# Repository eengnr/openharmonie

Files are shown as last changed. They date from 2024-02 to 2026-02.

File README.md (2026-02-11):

# openHARMONIE - OPEN source Home Automation ReMote cONtrol Infrared Emitter

⚠️ Work in progress ⚠️

## Goal

With this project the Logitech Harmony Hub should be rebuilt as a proof of concept.

It should be possible to start different activities (watch TV, watch Fire TV, watch Bluray, ...) from a web UI/app (virtual openHARMONIE remote), voice commands or a physical remote.

## Motivation and background

The Logitech Harmony was deprecated a few years ago, no new hardware is sold anymore. The servers are still running, but it's not clear how long this will be the case.

My home automation heavily relies on the integration of the Harmony into openHAB, e.g. to automatically dim/brighten lights if a stream is played on the Fire TV (done with complicated adb magic...).
Or to mute certain notification events on the LaMetric time while watching TV/streaming.

Additionally I have a complex setup with HDMI switches and splitters for sound and a self built Ambilight clone.

That's why I'm looking for an alternative. And what could be better than building it on my own :)

## Overview

- Logic implementation (which activity needs which devices in which states, ...) will be done with openHAB running on a Raspberry Pi 5.
- Sending of IR commands to devices will be done with a Raspberry Pi Zero W.
- Receiving of IR commands will also be done with the Pi Zero W.
- Communication between both Raspberrys will be done with MQTT.

### Current state of project

- ✅ Hardware setup
- ✅ MQTT setup
- ✅ Recording of IR commands from physical remotes
- ✅ Send remote control command from openHAB to a device
- ✅ Receive remote control command from additional physical remote
- ✅ Activity logic
- ✅ UI on smartphone (openHAB sitemaps)
- ✅ Voice commands
- 0️⃣ 3D printed housing
- 0️⃣ Refactor code to node modules
- 🚧 Refactor documentation and move to a repository
- ✅ Add pictures to the documentation
- 🚧 Bluetooth support

## Prerequisites

Building this is for experts and a good amount of time, nerves and coffee is necessary.
It took me almost three months to figure everything out and implement it.

### Skills and basic software setup

- openHAB (openHABian) is set up and running on Raspberry Pi 5 (Bookworm with openHAB 5.1.1)
- openHAB has the JavaScript binding installed and the openhab_rules_tools
- Knowledge about how to use openHAB is already available
- Raspbian Lite is set up and running on Raspberry Pi Zero W (Bullseye, Bookworm does not work properly for this as of March 2025!)
- Knowledge about basic Linux commands is already available
- Knowledge how to solder stuff on a circuit board is already available

### Necessary hardware

- Raspberry Pi 5 (or anything else where openHAB is running)
- Raspberry Pi Zero W
- Raspberry Pi Pico W (for optional Bluetooth)
- IR Receiver VS1838B
- IR LEDs (3 at least)
- some resistors
- 2N2222 transistor
- some (2-wire) cables
- circuit board for IR hardware
- Micro USB to Micro USB cable to connect the Zero and Pico
- soldering equipment
- spare remote control, e.g. from a no longer used TV (will be the "physical" openHARMONIE remote control)

## Basic MQTT Setup

- Broker (Mosquitto) is running on openHAB Raspberry Pi
- openHAB is Publisher (MQTT Client)
- Shell Script on Pi Zero W is Subscriber (MQTT Client)

Note: with this setup, you can easily add multiple Pi Zero W for different rooms and control them all from openHAB.

### Setup MQTT Broker (running on openHAB Raspberry Pi 5)

- Install `mosquitto`:

  `$ sudo apt update && sudo apt install mosquitto` (possible via openhabian-config as well)

- Configure mosquitto:

  `$ sudo vi /etc/mosquitto/conf.d/local.conf`

  Add lines:
    ```bash
    listener 1883
    allow_anonymous false
    password_file /etc/mosquitto/credentials
    ```

- Create credentials for openHAB client and shell script client (optional):

  `$ sudo mosquitto_passwd -b /etc/mosquitto/credentials pi pi`

  `$ sudo mosquitto_passwd -b /etc/mosquitto/credentials oh oh`

- Restart broker

  `$ sudo systemctl restart mosquitto`

### Setup openHAB MQTT (Client)

- Install MQTT Binding
- Add Bridge MQTT Broker with IP 127.0.0.1 and `oh`/`oh` as user/password
- Add Thing topic for sending IR commands to devices (topic to publish)
- Add a channel to this thing
- Add Thing topic for receiving IR commands from additonal hardware remote control (optional, topic to subscribe)
- Add a channel to this thing

Note: We use two separate topics instead of one topic with a commandTopic and stateTopic, because communcation is fire & forget. There is no direct "response" to the stateTopic after the commandTopic was published.

See `/etc/openhab/things/mqttopenharmonie.things`

- Create an item for the `Pi0WHarmonie` channel which can later be updated from rules
- Create an item for the `OHHarmonie` channel which can later be used to process context specific IR commands from the additional hardware remote

See `/etc/openhab/items/openharmonie.items`

### Setup Pi Zero W MQTT (Client)

- Install `mosquitto_sub`:

  `$ sudo apt install mosquitto-clients`

### Test the setup

Note: Use the IP of the openHAB Raspberry Pi where `mosquitto` is running instead of `broker.home`.

On Pi Zero W:

- Subscribe to the topic

  `$ mosquitto_sub -h broker.home -t devices/pi0w/harmonie -u pi -P pi`

In openHAB:

- Open API Explorer -> Items -> POST /items/{itemname} -> Try out
- Enter the item name `Send_Harmonie_Command` created above
- Enter string `hello world` in request body
- Execute (= publish to the topic)

➡️ `hello world` is shown on the Pi Zero W command line

## openHAB configuration

For openHAB we need several Things, Items and Rules. Additionally a Sitemap is necessary.

### Communication to Pi Zero W

- 2 String Items for publishing/subscribing to MQTT topics.
These necessary items were already created in the previous step for the MQTT setup.

### Physical remote controls

Necessary for each physical remote control belonging to a physical device:
- 1 Number Item which has all the buttons of the remote as metadata and updates the `Send_Harmonie_Command` MQTT String Item with the `DEVICE BUTTON` combination to be sent

  `TV_HISENSE_EN2BF27H_RemoteControl`, `BLURAY_PLAYER_PIONEER_RemoteControl`, ...

### Physical devices

Necessary for each physical device (TV, Receiver, HDMI switches ...)
- 1 Switch item for power state. The item only reflects the current power state, it is not used to control it.

  `TV_HISENSE_EN2BF27H_OnOff`, `BLURAY_PLAYER_PIONEER_OnOff`, ...

Note: if the "physical remote" number Item of the device is updated directly via UI (i.e. "a button is pressed on the physical remote"), the switch Item is NOT changed. That's how we can correct device status if IR commands failed

### Virtual openHARMONIE remote

- 1 Number item `OPENHARMONIE_RemoteControl` for the buttons on the virtual openHARMONIE remote, which will be used to control the devices based on the current activity

### Activities

Necessary for Activities (Watch TV, watch Fire TV, ...)
- 1 String Item "Activity starting" which gets an update as soon as an activity is starting

  `OPENHARMONIE_Activity_Starting`

- 1 String Item "Activity started" which gets an update as soon as an activity is fully started

  `OPENHARMONIE_Activity_Started`

Activites are triggered with the `Starting` item. This equals the activity starting channel of the real Harmony.
If the activity is started, we execute different phases and queue their tasks with a `Gatekeeper` from the `openhab_rules_tools`.
These phases are defined for each activity:

- `onExit`: tasks to do before the current activity is changed
- `powerStates`: tasks to set the correct power states for the new activity
- `inputStates`: tasks to set the correct input states for the new activity
- `onEnter`: tasks to do to finish starting the activity
- `onFinish`: tasks which can dynamically be added, e.g. to directly start a favorite TV programm or app

All possible activities are predefined in the metadata of the `OPENHARMONIE_Activity_Starting` item to be selected from the UI.

Activities can then be triggered either by buttons of the physical/virtual openHARMONIE or by voice commands (or anything else available in openHAB).

### Sitemap

We need some additional groups to add the virtual remotes of the devices to a sitemap.

See `/etc/openhab/etc/sitemaps/openharmonie.sitemap`

Note: The sitemap uses icons which are saved in `/etc/openhab/icons/classic`. This was the only way to get the icons in the openHAB Android app and in the Basic UI.

The sitemap includes a web view to load a CSS for the Basic UI.

Additionally, the sitemap uses light controls which are not part of the setup here.

### Voice commands

We need a group with switches which will be available via Matter. openHAB acts as a Matter Bridge and provides the switches.

See `/etc/openhab/etc/items/openharmonie.items`

### Rules

Necessary rules:
- Rule to send a remote control command to the Pi Zero W if a remote control button was pushed (`Remote_Control_Button_Pushed`) (= update MQTT Item with state if a remote control item changes its state)
- Rule to process an incoming IR command via MQTT from the physical openHARMONIE (`IR_Command_Received_Via_MQTT`)
- Rule to send a command to a target device if the button on the physical/virtual openHARMONIE was pushed (`openHARMONIE_Button_Pushed`)
- Rule to start an activity (`openHARMONIE_Activity_Starting`)
- Rule for voice commands (`openHARMONIE_Voice_Commands`)

Rules are written in JavaScript.

### Implementation

Note that some Items (e.g. groups for TV/Reciever, light controls) already exist in my setup from other configuration files.

#### Things

See `/etc/openhab/items/mqttopenharmonie.items`

#### Items

See `/etc/openhab/items/openharmonie.items`

#### JavaScript rule

See `/etc/openhab/automation/js/openharmonie.js`

#### Sitemaps

See `/etc/openhab/sitemaps/openharmonie.sitemap`

## Pi Zero W configuration

### Setup a non-root user

- Add a new user with name `openharmonie`

  `$ sudo adduser openharmonie`

- Enter `openharmonie` as password and confirm all other values

- Add the user to the groups `dialout` to send commands via serial connection

  `$ sudo adduser openharmonie dialout`

- Add the user to the group `video` to send commands via IR

  `$ sudo adduser openharmonie video`

Note: The files will be placed in the `pi` user home folder and owned for simplicity.

### Move `/tmp/` folder to RAM

Add the following line in `/etc/fstab`.

`$ sudo vi /etc/fstab`

```
tmpfs /tmp tmpfs defaults,size=64M 0 0
```

### Listener for MQTT commands

#### Shell script as MQTT client

A shell script `openharmonie.sh` is running on the Pi Zero W which is receiving MQTT updates and calls another script to send out IR commands (or adb commands for Fire TV).

The script watches if the `mosquitto_sub` process is still running every 5 seconds; if not, the script exits.

`$ touch ~/openharmonie/openharmonie.sh && chmod +x ~/openharmonie/openharmonie.sh`

See `/home/pi/openharmonie/openharmonie.sh`

#### Turn the MQTT shell script to a system service

- Create a new file `openharmonie.service` in `~/openharmonie`

  See `/home/pi/openharmonie/openharmonie.service`

- Copy the file to the `systemd` configuration folder

  `$ sudo cp openharmonie.service /etc/systemd/system`

- Reload the systemd configuration

  `$ sudo systemctl daemon-reload`

- Enable and start the mqtt subscriber service

  `$ sudo systemctl enable openharmonie.service`
  
  `$ sudo systemctl start openharmonie.service`

- Check that it's running

  `$ systemctl status openharmonie.service`
  ```
  ● openharmonie.service - MQTT Subscriber for remote control commands
      Loaded: loaded (/etc/systemd/system/openharmonie.service; enabled; vendor preset: enabled)
      Active: active (running) since Fri 2024-01-12 12:53:06 CET; 4s ago
    Main PID: 22855 (openharmonie.sh)
        Tasks: 5 (limit: 414)
          CPU: 94ms
      CGroup: /system.slice/openharmonie.service
              ├─22855 /bin/bash /home/pi/openharmonie/openharmonie.sh
              ├─22856 /bin/bash /home/pi/openharmonie/openharmonie.sh
              ├─22857 /bin/bash /home/pi/openharmonie/openharmonie.sh
              ├─22859 sleep 5
              ├─22860 mosquitto_sub -h broker.home -t devices/pi0w/harmonie -u pi -P pi
              └─22931 sleep .1

  Jan 03 13:35:20 pi0w systemd[1]: Started MQTT Subscriber for remote control commands.
  Jan 03 13:35:20 pi0w openharmonie.sh[18885]: Listening...
  ```

### Setup for infrared on Raspberry Pi Zero W

Note that `LIRC` is not necessary on Bullseye. Instead, the kernel already supports multiple IR protocols.

Receiving/sending can be done with `ir-keytable` and `ir-ctl` on Bullseye.

#### Hardware setup

##### Record commands

- VS1838B IR Receiver

1) Connect VCC of IR Receiver to Raspberry Pi Zero W GPIO 5V
2) Connect GND of IR Receiver to Raspberry Pi Zero W GPIO Ground
3) Connect OUT of IR Receiver to Raspberry Pi Zero W GPIO 17

##### Send commands

- 5mm IR Emitter LED (IF = 20 mA, UF = 1.2 to 1.5 V)
- Resistor with (5 V - 1.2 V) / 20 mA = 175 to 190 Ohm (1.5 to 1.2 V LED voltage range)
- 2N2222 transistor
- 1 kOhm resistor for transistor

Connect IR LED to 5 V pin and use a transistor as switch. The transistor is toggled by the GPIO 18 pin.
1) Connect the 190 Ohm resistor to 5 V pin
2) Connect anode of LED to resistor
3) Connect cathode of LED to collector of 2N2222 transistor
4) Connect emitter of transistor to GND pin
5) Connect 1 kOhm resistor to GPIO 18 and base of transistor

Note: You can use three IR Emitter LEDs in a row. The resistor then has to be changed to be in the range of 27 - 75 Ohm (1.5 to 1.2 V LED voltage)
If more than three LEDs are necessary, they have to be put parallel to the existing three. More current is then drawn from the 5 V pin. Research needs to be done how high this current can be :)

##### Wiring diagram

Wiring Diagram

The wiring diagram shows the setup with three IR leds and two resistors with 22 and 10 Ohm.

#### Software setup

##### Enable GPIO pins

- Boot Raspberry Pi Zero W and edit the boot config with the editor of your choice, e.g.

  `$ sudo vi /boot/config.txt`

- Uncomment lines:

  ```
  dtoverlay=gpio-ir,gpio_pin=17
  dtoverlay=gpio-ir-tx,gpio_pin=18
  ```

- Save & exit vi, then reboot

The IR Receiver and IR LED are now controllable with GPIO pin 17 and 18.

##### Setting up symlinks for /dev/lirc0 and /dev/lirc1

The IR receiver/sender devices are randomly assigned at boot by the kernel to devices `/dev/lirc0` and `/dev/lirc1`, that's why we create symlinks for them.
With the symlinks, we have a static name for the devices.

- Get attributes for `/dev/lirc0`

  `$ udevadm info --attribute-walk --path $(udevadm info --query path --name=/dev/lirc0)`

- Get attributes for `/dev/lirc1`

  `$ udevadm info --attribute-walk --path $(udevadm info --query path --name=/dev/lirc1)`

With this we get the `DRIVERS=="gpio_ir_recv"` and `DRIVERS=="gpio-ir-tx"`.

Note the dashes and minus for the DRIVERS!

With this information, we can create a udev configuration file.

- Create a file `/etc/udev/rules.d/80-lirc.rules` with the following content:

  `$ sudo vi /etc/udev/rules.d/80-lirc.rules`
    ```
    SUBSYSTEM=="lirc", KERNEL=="lirc*", DRIVERS=="gpio-ir-tx", SYMLINK+="lirc-tx"
    SUBSYSTEM=="lirc", KERNEL=="lirc*", DRIVERS=="gpio_ir_recv", SYMLINK+="lirc-recv"
    ```

- Then save and exit and reboot the Pi.

  `$ sudo reboot`

After the reboot, the IR receiver should be available at `/dev/lirc-recv` and the IR sender should be available at `/dev/lirc-tx`.

```bash
$ ls -l /dev/lirc*
crw-rw---- 1 root video 251, 0 Dec 30 09:56 /dev/lirc0
crw-rw---- 1 root video 251, 1 Dec 30 09:56 /dev/lirc1
lrwxrwxrwx 1 root root       5 Dec 30 09:56 /dev/lirc-recv -> lirc1
lrwxrwxrwx 1 root root       5 Dec 30 09:56 /dev/lirc-tx -> lirc0
```
We can now use `/dev/lirc-tx` to send IR signals and `/dev/lirc-recv` to receive commands.

##### Record IR commands

- Install `ir-keytable`

  `$ sudo apt install ir-keytable`

Note: at time of writing, version `1.20.0` of `ir-keytable` is used.

- Confirm it's running

  `$ ir-keytable`
    ```bash
    Found /sys/class/rc/rc1/ with:
        Name: gpio_ir_recv
        Driver: gpio_ir_recv
        Default keymap: rc-rc6-mce
        Input device: /dev/input/event0
        LIRC device: /dev/lirc1
        Attached BPF protocols: Operation not permitted
        Supported kernel protocols: lirc rc-5 rc-5-sz jvc sony nec sanyo mce_kbd rc-6 sharp xmp imon
        Enabled kernel protocols: lirc rc-5 rc-5-sz jvc sony nec sanyo mce_kbd rc-6 sharp xmp imon
        bus: 25, vendor/product: 0001:0001, version: 0x0100
        Repeat delay = 500 ms, repeat period = 125 ms
    ```

In the example above, the IR receiver is recognized as `/dev/lirc1` and available via the kernel as `rc1`.
This may change after each reboot. We use `rc1` for the following commands.

- Enable all supported kernel protocols for the test

  `$ sudo ir-keytable -p all -s rc1`

- Start the `ir-keytable` test and send an IR command from the remote to the IR receiver.
This is the input of the IR receiver already passed through the kernel.

  ```bash
  $ ir-keytable -t -s rc1
  Testing events. Please, press CTRL-C to abort.
  1253.120088: lirc protocol(rc5): scancode = 0x1c3d toggle=1
  1253.120135: event type EV_MSC(0x04): scancode = 0x1c3d
  1253.120135: event type EV_SYN(0x00).
  1253.230098: lirc protocol(rc5): scancode = 0x1c3d toggle=1
  1253.230144: event type EV_MSC(0x04): scancode = 0x1c3d
  1253.230144: event type EV_SYN(0x00).
  1254.250104: lirc protocol(rc5): scancode = 0x1c3b
  1254.250150: event type EV_MSC(0x04): scancode = 0x1c3b
  1254.250150: event type EV_SYN(0x00).
  1255.440082: lirc protocol(rc5): scancode = 0x1c1f toggle=1
  1255.440121: event type EV_MSC(0x04): scancode = 0x1c1f
  1255.440121: event type EV_SYN(0x00).
  ...
  ```

Test different keys of remote. If the the keycodes are different for different remote control buttons, the kernel can decode the IR signal.

➡️ See section "Codes for supported remotes"

If the keycodes are the same for every button, then the kernel does not support the remote protocol and raw codes need to be captured

➡️ See "Raw codes for unsupported remotes"

###### Codes for supported remotes

If the kernel supports the remote control protocol, the key codes can be written down in a `toml` configuration file for each remote.

While running `$ ir-keytable -t -s rc1`, press each button of the remote and note down its hex code and the protocol of the remote (see example above).
The kernel already decodes the IR command.
Write this into a `toml` file for your remote, e.g.

`/home/pi/openharmonie/remotes/toml/HAUPPAUGE_PTR005.toml`

If a remote sends two codes for each button press, we can note them as e.g. `REMOTE_POWER_1` and `REMOTE_POWER_2` in the `toml` file.

Note: the `toml` file can also be loaded to the kernel. Then it's possible to react to the IR control on the Raspberry Pi, e.g. power down the Raspberry Pi when `KEY_POWER` is pressed. If you want to control the Raspberry Pi with a remote control, you have to give key/button names which the kernel can map to commands (e.g. KEY_POWER will shut down the Pi).

We will use this to receive IR commands from a remote control which is not used by any device. The IR command received on the Pi Zero W can be sent to openHAB via MQTT and from there we can execute context specific commands. E.g. send back play/pause depending on the current activity to either the cable receiver, the Fire TV or the Bluray player via MQTT to the Pi Zero W.

###### Raw codes for unsupported remotes

If the kernel does not support the remote control protocol, the raw IR signal needs to be captured and transmitted. Capturing/sending has to be done in the `mode2` format. I couldn't get `toml` files with raw codes working.

All in all capturing the raw signals was really challenging most likely because of the "analogue" path from original remote control to the IR receiver.

- Capture a button press to a file in mode2 format

  `$ ir-ctl -d /dev/lirc-recv --mode2 --receive=REMOTE_POWER.txt`

- After the button on the remote was pressed, end the recording with `Ctrl+c`.

The file `REMOTE_POWER.txt` then contains multiple raw IR signals which consist of `pulse` and `pause` lines and are separated by a `timeout` between two signals.
The `timeout` is ignored during sending.

After the file for one button was recorded, test immediately if the signal can be sent to the device, see section "Sending commands not supported by the kernel" below.

If the device does not react correctly or not at all, try to record the raw signal again (e.g. try with longer/shorter button press). Repeat this until the device recognizes the command.

This can be really annoying and I had to capture the signals of the buttons several times until the signals were properly received at the device.

For some buttons, I even recorded their signal 10-20 times in separate files for each button press. Then I checked which of the files could be used to send the command to the device. From these files, I calculated the average pulse/pause length of each pulse/pause line and saved this in a new file. Then I tested if this "average length" file could be used to send the command, which was fortunately always ok.

##### Send IR commands

Sending is done with `ir-ctl`.

###### Sending commands supported by the kernel

Sending a code can be done with:

  `$ ir-ctl -d /dev/lirc-tx -k TV_HISENSE_EN2BF27H.toml -K REMOTE_POWER`

The configuration file and the button need to be passed.

If a remote sends two codes for a button press, we have to add them both with another `-K`:

  `$ ir-ctl -d /dev/lirc-tx -k BLURAY_PLAYER_PIONEER.toml -K BUTTON_1 -K BUTTON_2`

###### Sending raw commands not supported by the kernel

Sending a code can be done with:

  `$ ir-ctl -d /dev/lirc-tx --send=KEY_NAME.txt`

The file with the pulses and spaces needs to be passed.

##### Wrapper script to send commands of different remote controls

Now we bring all of this together in one script which can be called by the MQTT subscriber script running on the Raspberry Pi Zero W.

To realize this, put all files in a folder with the following structure. Supported remotes are put into the `toml` folder, unsupported remotes are put in the `raw` folder.

Additionally, for each device a shell script is written which gets the key name passed. In the script, the correct amount of codes to be sent has to be configured. Make the scripts executable with `chmod`.
Files which were not explained yet will be covered later.

```bash
~
|
- openharmonie
  |
  - mqttsubscriber.sh
  - mqttsubscriber.service
  |
  - remotes
    |
    - toml
    | |
    | - TV_HISENSE_EN2BF27H.toml
    | - BLURAY_PLAYER_PIONEER.toml
    | ...
    - raw
    | |
    | - RECEIVER_SAMSUNG_KD
    | | |
    | | - REMOTE_POWER.txt
    | | - REMOTE_MENU.txt
    | | - ...
    | - ...
    - thd
    | |
    | - openharmonie.conf
    |
    - keys
    | |
    | - keymap.sh
    | - keymap_fallback.sh
    |
    - receive_command.sh
    - send_command.sh
    - TV_HISENSE_EN2BF27H.sh
    - BLURAY_PLAYER_PIONEER.sh
    - RECEIVER_SAMSUNG_KD.sh
    - FIRETV.sh
    ...
```

Examples for different types of devices.

1) Remote control with raw codes:

    `/home/pi/openharmonie/remotes/RECEIVER_SAMSUNG_KD.sh`

2) Remote control with kernel supported codes:

    `/home/pi/openharmonie/remotes/TV_HISENSE_EN2BF27H.sh`

3) Remote control with mixed button behavior:

    - buttons which send a code `0xa6a7` first
    - buttons which send a code `0xa6a0` first
    - buttons which send the code once
    - buttons wich send the code twice

    `/home/pi/openharmonie/remotes/BLURAY_PLAYER_PIONEER.sh`

Additonally we create a `send_command.sh` shell script which is called from the MQTT listener:

  `$ touch ~/remotes/send_command.sh && chmod +x ~/remotes/send_command.sh`

  See `/home/pi/openharmonie/remotes/send_command.sh`

##### Receive IR commands from additional remote

An additional remote will be used to control the whole system depending on the current activity. For this we use a spare remote, e.g. from a device which is no longer used.

###### Reacting to IR input

- Create a `toml` file for this additional remote.
  See `/home/pi/openharmonie/remotes/toml/OPENHARMONIE_TV_PHILIPS.toml`

Note: To not control the Raspberry Pi Zero W with the button presses, we have to choose button names which are not used by the Linux system.
I chose `BTN_TRIGGER_HAPPY` keys and `KEY_MACRO` keys.

- To permanently load this file after a reboot, copy it to the folder `/etc/rc_keymaps`

  `$ sudo cp /home/pi/openharmonie/remotes/toml/OPENHARMONIE_TV_PHILIPS.toml /etc/rc_keymaps`

- Then add it in the `rc_maps.cfg`

  `$ sudo vi /etc/rc_maps.cfg`

  Add the following line to the existing maps:
  ```
  ...
  # Table to automatically load the rc maps for the bundled IR's provided with the
  # devices supported by the linux kernel

  #driver table                    file
  gpio_ir_recv    *       OPENHARMONIE_TV_PHILIPS.toml
  ...
  ```

Now the IR commands sent by the remote can be processed as input events.

###### Processing input events with triggerhappy

Processing the input events is done with `triggerhappy`. The same keycodes have to be used like in the openHARMONIE `toml` file.

- Create a configuration file for `triggerhappy`

  `/home/pi/openharmonie/remotes/thd/openharmonie.conf`

- Copy the file to the triggerhappy config folder

  `$ sudo cp /home/pi/openharmonie/remotes/thd/openharmonie.conf /etc/triggerhappy/triggers.d`

- Restart the triggerhappy service

  `$ sudo systemctl restart triggerhappy.service`

Every input event triggered by the remote executes the `receive_command.sh` with the generic button name.

###### Forwarding input events via MQTT

Forwarding the button name via MQTT to openHAB can be done with a script.

- Create it in the remotes folder

  `$ touch ~/remotes/receive_command.sh && chmod +x ~/remotes/receive_command.sh`

  See `/home/pi/openharmonie/remotes/receive_command.sh`

Note: If using DNS names to communicate with the MQTT broker, it's recommended to install `dnsmasq` to have a DNS cache.
Otherwise, each time the `mosquitto_pub` is called a DNS lookup is necessary which can cost time.

  `$ sudo apt install dnsmasq`

Then reboot the Pi Zero W. If everything works, you should see an update of the `Receive_Harmonie_Command` item after pressing a button on the remote.

### Setup connection to Fire TV

The Fire TV can be controlled with adb and Bluetooth.
We will use a mixture depending on the commands.

- Install `adb` on the Pi Zero W

  `$ sudo apt install adb`

- Start the Fire TV and activate developer options somewhere in the settings menu

- Execute the following command to initialize the connection

  `adb connect firetv.home:5555`

  Note: Change `firetv.home` to the IP address of your Fire TV

- A popup is shown on the Fire TV, make sure to set the checkmark and accept the incoming connection.

From now on, we can connect to adb, execute commands and disconnect if the Fire TV is not used.

To control the Fire TV, we will use `adb shell sendevent` to send keycodes to the keyboard input device available on the Fire TV.

This is faster than `adb shell input keyevent` because it doesn't use the Java layer of Android.

Note: This input device `amzkeyboard` suddenly disappeared from my Fire TV after a few days. That's why I added the `input keyevent` as fallback.

With `adb shell sendevent` we can send the key codes available from the Linux kernel: https://github.com/torvalds/linux/blob/master/include/uapi/linux/input-event-codes.h

If the `amzkeyboard` input is not available, we use `input keyevent` as fallback. For this we need to map the key codes of the Linux kernel to the key events of Android: https://developer.android.com/reference/android/view/KeyEvent

To start specific apps, we will use `adb shell am start`.

- Create a shell script for Fire TV commands on the Pi Zero W and make it executable

  `$ touch ~/remotes/FIRETV.sh && chmod +x ~/remotes/FIRETV.sh`

  See `/home/pi/openharmonie/remotes/FIRETV.sh`

- Additionally create two keymap files to look up the numbers of the key names. One for the Linux key codes, the other one to map them to Android key events.

  See `/home/pi/openharmonie/remotes/keys/keymap.sh` and `/home/pi/openharmonie/remotes/keys/keymap_fallback.sh`

Note: The correct activites for apps can be found via adb:

- Connect to the Fire TV

  `$ adb connect firetv.home:5555`

- Search the package name, e.g. for an app called `streamingapp`

  `$ adb shell pm list packages | grep streamingapp`

- If the app cannot be found, list all packages and search it manually

  `$ adb shell pm list packages`

- Get the activity

  `$ adb shell cmd package resolve-activity --brief com.mystreamingapp.app`

- If no activity can be found, try

  `$ adb shell pm dump com.mystreamingapp.app | grep -A 1 "MAIN" | grep com.mystreamingapp.app`

Note: the supported keycodes for the `amzkeyboard` input can be found with
`$ adb shell getevent -lp`

Note:
Sending the `input keyevent` is quite slow, because the `input.jar` needs to be started every time.
Sending an event with `sendevent` is faster, but for this the virtual keyboard must be available.
As an alternative to the virtual keyboard, the `sendevent` can be sent to the device which appears if the Fire TV remote was used.
But this is not always available.
The best way to control the Fire TV is via Bluetooth. The `FIRETV.sh` tries to use the best available way to send the commands.

### Setup Linux laptop

If `HDMI` is started as activity, a Linux laptop can be controlled.
To be able to do this, `ydotool` needs to be installed on the Linux laptop and `ssh` access from the Pi Zero W to the laptop needs to be set up.

On the Linux laptop:

- Install `ydotool`

  `$ sudo apt update && sudo apt install ydotool`

On the Pi Zero W:

- Login as `openharmonie`

  `$ su - openharmonie`

- Create a ssh key

  `$ ssh-keygen -t ed25519 -C "openharmonie"`

- Copy the public key to the laptop (exchange user and host accordingly)

  `$ ssh-copy-id user@linux.home`

- Create an alias

  `$ vi .ssh/config`
  ```
  Host linux
      User user
      IdentityFile ~/.ssh/id_ed25519
      HostName linux.home
      PreferredAuthentications publickey
  ```

- Logout from `openharmonie`

  `$ exit`

## Pi Pico W configuration

The Pi Pico W acts as a Bluetooth keyboard to send commands to a Fire TV.
It receives the key to send via a serial USB connection from the Pi Zero W.
With the provided sketch, it's possible to pair and connect only one device.

See `openHARMONIE.ino`.

TODO: Make it possible to pair multiple devices and connect only the one which is relevant for the current activity.

### Flash software to Pi Pico W

- Download and install Arduino IDE: https://www.arduino.cc/en/software

- Open Arduino IDE and go to `File` > `Preferences...` > `Additional Boards Manager URLs`. Paste `https://github.com/earlephilhower/arduino-pico/releases/download/global/package_rp2040_index.json` there and click `OK`.

- Open the `openHARMONIE.ino` sketch.

- Go to `Tools` > `Board` > `Boards Manager...`, search for `Raspberry Pi Pico` and click `INSTALL`.

- Connect the Pico W with a USB cable to your computer which is running Arduino IDE.

- In the `Select Board` dropdown, go to `Select Other Board and Port`, select `Raspberry Pi Pico W` in the Boards list. The port should be discoverd as `/dev/ttyACM0` on Linux.

- Go to `Tools` > `IP/Bluetooth Stack` and select `IPv4 + Bluetooth`.

- Click the `Verify` checkmark and if no errors are shown, click the `Upload` checkmark to flash the code to the Pi Pico W.

- After this you should see a device `openHARMONIE` e.g. in the Bluetooth pairing menu of your mobile phone (but don't connect to it).

### Add named device to Pi Zero W

Simlar to the IR sender/receiver devices a named device for the serial connection between Pi Zero W and Pi Pico W is created.

- Create a file `/etc/udev/rules.d/80-pico.rules` with the following content:

  `$ sudo vi /etc/udev/rules.d/80-pico.rules`
    ```
    KERNEL=="tty*", ATTRS{manufacturer}=="Raspberry Pi", ATTRS{product}=="Pico W", SYMLINK+="picow"
    ```

- Then save and exit and shut down the Pi Zero W.

- Connect the Pi Zero W and Pi Pico W with a Micro USB to Micro USB cable. Use the USB port on the Pi Zero W which is not used for power.

- Start up the Pi Zero W. The serial device should be available as `/dev/picow` and can be used by the `FIRETV.sh`.

### Connect Fire TV to Bluetooth device

- In the settings of the Fire TV, go to Bluetooth and game controllers and search for a new device named `openHARMONIE`.

- Connect to it!

## Voice commands integration

To make everything controllable from voice commands, the Matter binding needs to be installed in openHAB.
Please check the documentation how to install it and connect it to your voice assistant, e.g. an Amazon Echo, Google Nest or Apple Homepod.

After installation of the Matter binding, openHAB acts as a Matter bridge and can expose items to the Matter fabric.

For every command (e.g. start an activity, start a favorite, pause, play, ...) we need a Switch item with Matter `OnOffLight` metadata.

Note: It's only possible to expose lights or power outlets as controlees via Matter.

The switch items are part of a group and the items can then be discovered e.g. in the Alexa app. Afterwards, if necessary a routine can be created for a specific switch as voice command.

E.g. for "Pause with openHARMONIE" create a routine which then turns the "Pause" toggle to ON and so on.

The same should be possible with a Google Nest or Apple Homepod.

## Starting up

After everything is configured and set up, place the Raspberry Pi Zero W somewhere where it has WIFI access and point the IR LEDs towards your devices.
It's best if the distance to the devices is short.

Then have fun with your new setup!

## Images

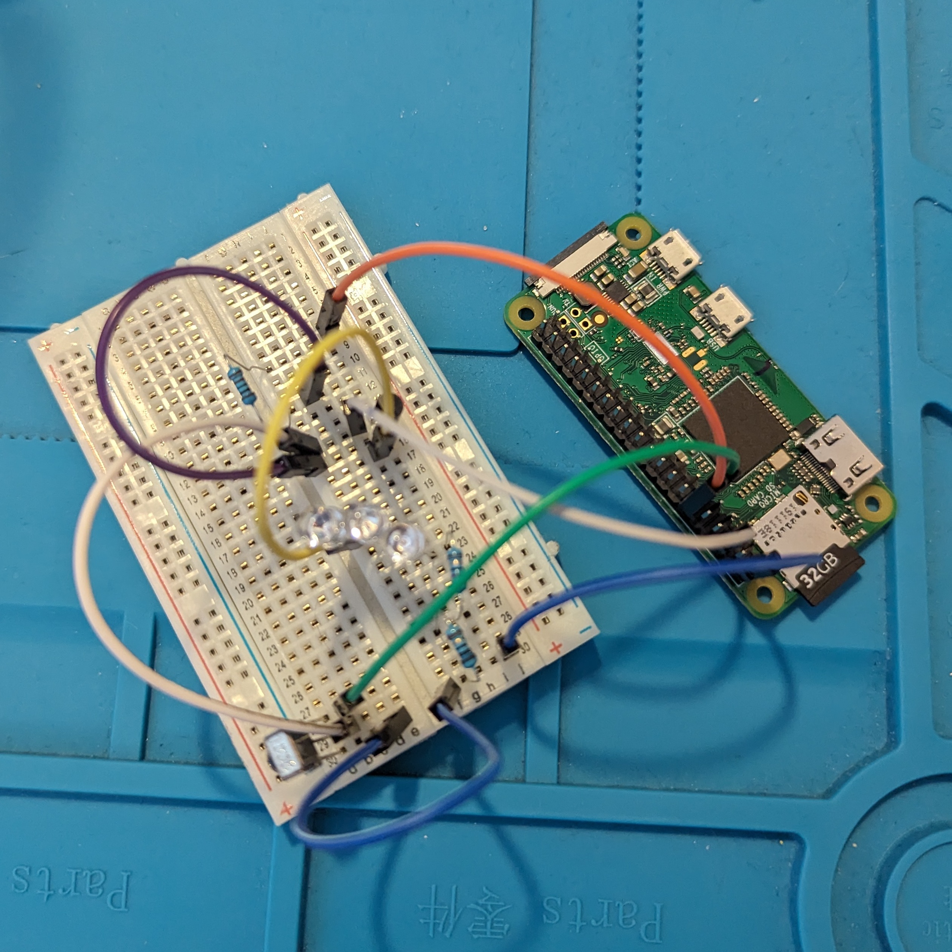
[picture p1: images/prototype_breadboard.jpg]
Prototype with breadboard

Prototype with breadboard

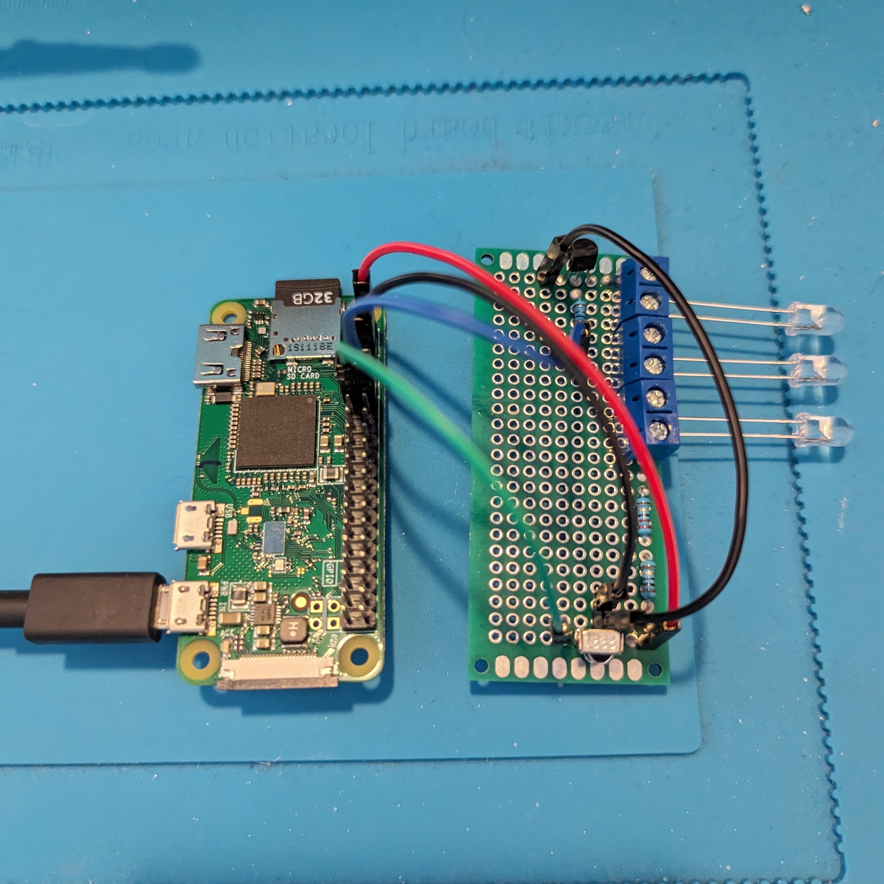
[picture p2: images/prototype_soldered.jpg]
Prototype soldered on board

Prototype soldered on board

## License

```
This program is free software: you can redistribute it and/or modify
it under the terms of the GNU General Public License as published by
the Free Software Foundation, either version 3 of the License, or
(at your option) any later version.

This program is distributed in the hope that it will be useful,
but WITHOUT ANY WARRANTY; without even the implied warranty of
MERCHANTABILITY or FITNESS FOR A PARTICULAR PURPOSE.  See the
GNU General Public License for more details.

You should have received a copy of the GNU General Public License
along with this program.  If not, see <https://www.gnu.org/licenses/>.
```

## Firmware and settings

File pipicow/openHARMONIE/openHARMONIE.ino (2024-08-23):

#include <KeyboardBLE.h>

// https://usb.org/hid
// https://usb.org/sites/default/files/hut1_5.pdf -> Consumer page 0x0C, send with consumerPress()
#define KEY_FASTFORWARD 0xB3
#define KEY_REWIND 0xB4
#define KEY_CHANNELUP 0x9C
#define KEY_CHANNELDOWN 0x9D

struct KeyMapping
{
  const char *name;
  uint8_t key;
};

struct ConsumerKeyMapping
{
  const char *name;
  uint16_t key;
};

KeyMapping keyMappings[] = {
    {"KEY_UP_ARROW", KEY_UP_ARROW},
    {"KEY_DOWN_ARROW", KEY_DOWN_ARROW},
    {"KEY_LEFT_ARROW", KEY_LEFT_ARROW},
    {"KEY_RIGHT_ARROW", KEY_RIGHT_ARROW},
    {"KEY_LEFT", KEY_LEFT_ARROW},
    {"KEY_UP", KEY_UP_ARROW},
    {"KEY_RIGHT", KEY_RIGHT_ARROW},
    {"KEY_DOWN", KEY_DOWN_ARROW},
    {"KEY_KPENTER", KEY_KP_ENTER},
    //{"KEY_PROGRAM", },
    {"KEY_ESC", KEY_ESC},
    // Add more mappings for more functions
};

ConsumerKeyMapping consumerKeyMappings[] = {
    {"KEY_SEARCH", KEY_AC_SEARCH},
    {"KEY_REWIND", KEY_REWIND},
    {"KEY_PLAYPAUSE", KEY_PLAY_PAUSE},
    {"KEY_FASTFORWARD", KEY_FASTFORWARD},
    {"KEY_POWER", KEY_POWER},
    {"KEY_BACK", KEY_AC_BACK},
    {"KEY_HOMEPAGE", KEY_AC_HOME},
    {"KEY_MENU", KEY_MENU},
    {"KEY_MUTE", KEY_MUTE},
    {"KEY_VOLUMEUP", KEY_VOLUME_INCREMENT},
    {"KEY_VOLUMEDOWN", KEY_VOLUME_DECREMENT},
    {"KEY_CHANNELUP", KEY_CHANNELUP},
    {"KEY_CHANNELDOWN", KEY_CHANNELDOWN},
};

const int numMappings = sizeof(keyMappings) / sizeof(KeyMapping);
const int consumerNumMappings = sizeof(consumerKeyMappings) / sizeof(ConsumerKeyMapping);

void setup()
{
  Serial.begin(9600);
  KeyboardBLE.begin("openHARMONIE", "openHARMONIE", KeyboardLayout_en_US);
  Serial.println("Keyboard BLE started");
  delay(5000);
}

//Main loop going through all the keys, then waiting 10ms
void loop()
{
  while (Serial.available())
  {
    String input = Serial.readStringUntil('\n');
    input.trim();
    bool found = false;
    for (int i = 0; i < numMappings; i++)
    {
      if (input.equalsIgnoreCase(keyMappings[i].name))
      {
        KeyboardBLE.press(keyMappings[i].key);
        delay(50);
        KeyboardBLE.release(keyMappings[i].key);
        found = true;
        break;
      }
    }
    if (found)
    {
      continue;
    }
    for (int i = 0; i < consumerNumMappings; i++)
    {
      if (input.equalsIgnoreCase(consumerKeyMappings[i].name))
      {
        KeyboardBLE.consumerPress(consumerKeyMappings[i].key);
        delay(50);
        KeyboardBLE.consumerRelease();
        found = true;
        break;
      }
    }
    if (found)
    {
      continue;
    }
    if (input.equalsIgnoreCase("REMOTE_DISCONNECT"))
    {
      KeyboardBLE.end();
      continue;
    }
    if (input.equalsIgnoreCase("REMOTE_CONNECT"))
    {
      KeyboardBLE.begin("openHARMONIE", "openHARMONIE", KeyboardLayout_en_US);
      continue;
    }
    Serial.println("KEY unknown");
  }
  delay(10);
}

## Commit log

2024-02-02 Add images
    [openHARMONIE.fzz]
2024-08-23 Switch from named pipe to file to avoid blocking
2025-03-23 Make power and input state commands more robust and add voice commands to correct them
2026-01-05 Switch to internal power state/input state handling, improve timings, add Laptop control
